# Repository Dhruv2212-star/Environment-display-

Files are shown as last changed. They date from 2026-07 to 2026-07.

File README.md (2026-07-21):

**The project is divided into 8 major parts**  
lets understand each component's function one by one in a block to see what function they have in the circuit.   
1. Block 1 – USB Input & Protection  

| Ref | Component | Role in the Circuit |
| --- | --- | --- |
| J1  | USB-C Receptacle | Receives 5 V power and USB data from the host PC. |
| D1  | TVS Diode | Protects the board from ESD and voltage spikes coming through the USB connector. |
| F1  | Polyfuse | Limits current during short circuits and protects the USB port from overcurrent damage. |
| R1  | 5.1 kΩ | USB-C CC1 pull-down resistor to advertise the board as a power sink. |
| R2  | 5.1 kΩ | USB-C CC2 pull-down resistor to advertise the board as a power sink. |

2. Block 2 – 3.3 V Power Supply

| Ref | Component | Role in the Circuit |
| --- | --- | --- |
| U1  | TPS62162 | Converts the USB 5 V input into a stable 3.3 V supply with high efficiency. |
| L1  | 2.2 µH Inductor | Stores energy during switching and smooths the regulator output current. |
| C1  | 10 µF | Input bulk capacitor that stabilizes the 5 V input to the regulator. |
| C2  | 100 nF | High-frequency input bypass capacitor that filters switching noise. |
| C4  | 4.7 µF | Main output capacitor that stabilizes the 3.3 V output voltage. |
| C9  | 100 µF | Bulk output capacitor that supplies transient current to the ESP32 and peripherals. |
| R3  | 100 kΩ | Feedback resistor used by the regulator to maintain the correct output voltage. |

3. Block 3 – USB to UART Interface  

| Ref | Component | Role in the Circuit |
| --- | --- | --- |
| U2  | CP2102N | Converts USB communication into UART for programming and serial communication with the ESP32. |
| C3  | 100 nF | Decouples the CP2102N supply to reduce high-frequency noise. |
| C5  | 1 µF | Stabilizes the USB VBUS supply for the CP2102N. |
| C6  | 1 µF | Stabilizes the internal regulator output of the CP2102N. |

4. Block 4 – ESP32 Auto-Programming Circuit  

| Ref | Component | Role in the Circuit |
| --- | --- | --- |
| Q1  | MMBT3904 | Uses the RTS signal to automatically reset the ESP32. |
| Q2  | MMBT3904 | Uses the DTR signal to place the ESP32 into bootloader mode automatically. |
| R11 | 10 kΩ | Pull-up resistor for the ESP32 EN pin. |
| R12 | 10 kΩ | Pull-up resistor for the ESP32 GPIO0 (BOOT) pin. |
| SW1 | Push Button | Manual reset button for the ESP32. |
| SW2 | Push Button | Manual bootloader button for programming mode. |

5. Block 5 – ESP32 Module  

| Ref | Component | Role in the Circuit |
| --- | --- | --- |
| U3  | ESP32-WROOM-32E | Main microcontroller that reads sensors, stores data, communicates over USB, and controls the entire system. |
| C10 | 100 nF | Local decoupling capacitor placed close to the ESP32 power pin. |
| C11 | 100 nF | Additional high-frequency decoupling capacitor for stable ESP32 operation. |
| C16 | 10 µF | Bulk capacitor that supports sudden current demands from the ESP32's Wi-Fi and Bluetooth radio. |

6.  Block 6 – Environmental Sensors

(a) BME280  

| Ref | Component | Role in the Circuit |
| --- | --- | --- |
| U4  | BME280 | Measures temperature, humidity, and atmospheric pressure. |
| C12 | 100 nF | Filters supply noise to improve sensor accuracy. |

(b)  BH1750  

| Ref | Component | Role in the Circuit |
| --- | --- | --- |
| U4  | BME280 | Measures temperature, humidity, and atmospheric pressure. |
| C12 | 100 nF | Filters supply noise to improve sensor accuracy. |

(c) RTC  

| Ref | Component | Role in the Circuit |
| --- | --- | --- |
| U6  | DS3231M | Maintains accurate date and time, even when USB power is removed. |
| BT1 | CR2032 Battery | Keeps the RTC running during power loss. |
| C15 | 100 nF | Decouples the RTC power supply. |

7. Block 7 – microSD Storage  

| Ref | Component | Role in the Circuit |
| --- | --- | --- |
| J3  | MicroSD Socket | Stores logged environmental data on a removable SD card. |
| R9  | Pull-up resistor | Pulls the Card Detect line to a defined logic level when no card is inserted. |

8. Block 8 – User Interface

| Ref | Component | Role in the Circuit |
| --- | --- | --- |
| J2  | OLED Header | Connects the external OLED display over the I²C bus. |
| D2  | Status LED  | Indicates board status such as power or firmware activity. |
| R10 | 1 kΩ | Limits current through the status LED to protect it from excessive current. |

# Schematic 
schematic

# Final traced PCB 

PCB traced

# 3D view of the assumed PCB look 

3D png

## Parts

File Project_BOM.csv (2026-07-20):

Reference | Value | Quantity
R4 | 1 kΩ | 1
R5, R6, R11, R12 | 10 kΩ | 4
C1, C3, C4, C10 | 10 µF | 4
R3 | 100 kΩ | 1
C2, C6, C8, C9, C11, C12 | 100 nF | 6
L1 | 2.2 µH | 1
R10 | 330 Ω | 1
R7, R8 | 4.7 kΩ | 2
C5, C7 | 4.7 µF | 2
R1, R2 | 5.1 kΩ, 1% | 2
U4 | BME280 | 1
BT1 | Battery_Cell | 1
C13, C14, C15, C16 | C | 4
U2 | CP2102N-Axx-xQFN20 | 1
J2 | Conn_01x04 | 1
J4 | Conn_01x04_Pin | 1
J5 | Conn_01x06_Pin | 1
U6 | DS3231M | 1
D1 | D_TVS | 1
U3 | ESP32-WROOM-32 | 1
D2 | LED | 1
Q1, Q2 | MMBT3904 | 2
J3 | Micro_SD_Card_Det1 | 1
F1 | Polyfuse | 1
R9 | R | 1
SW1, SW2 | SW_Push | 2
J1 | USB_C_Receptacle | 1
U1, U5 | ~ | 2

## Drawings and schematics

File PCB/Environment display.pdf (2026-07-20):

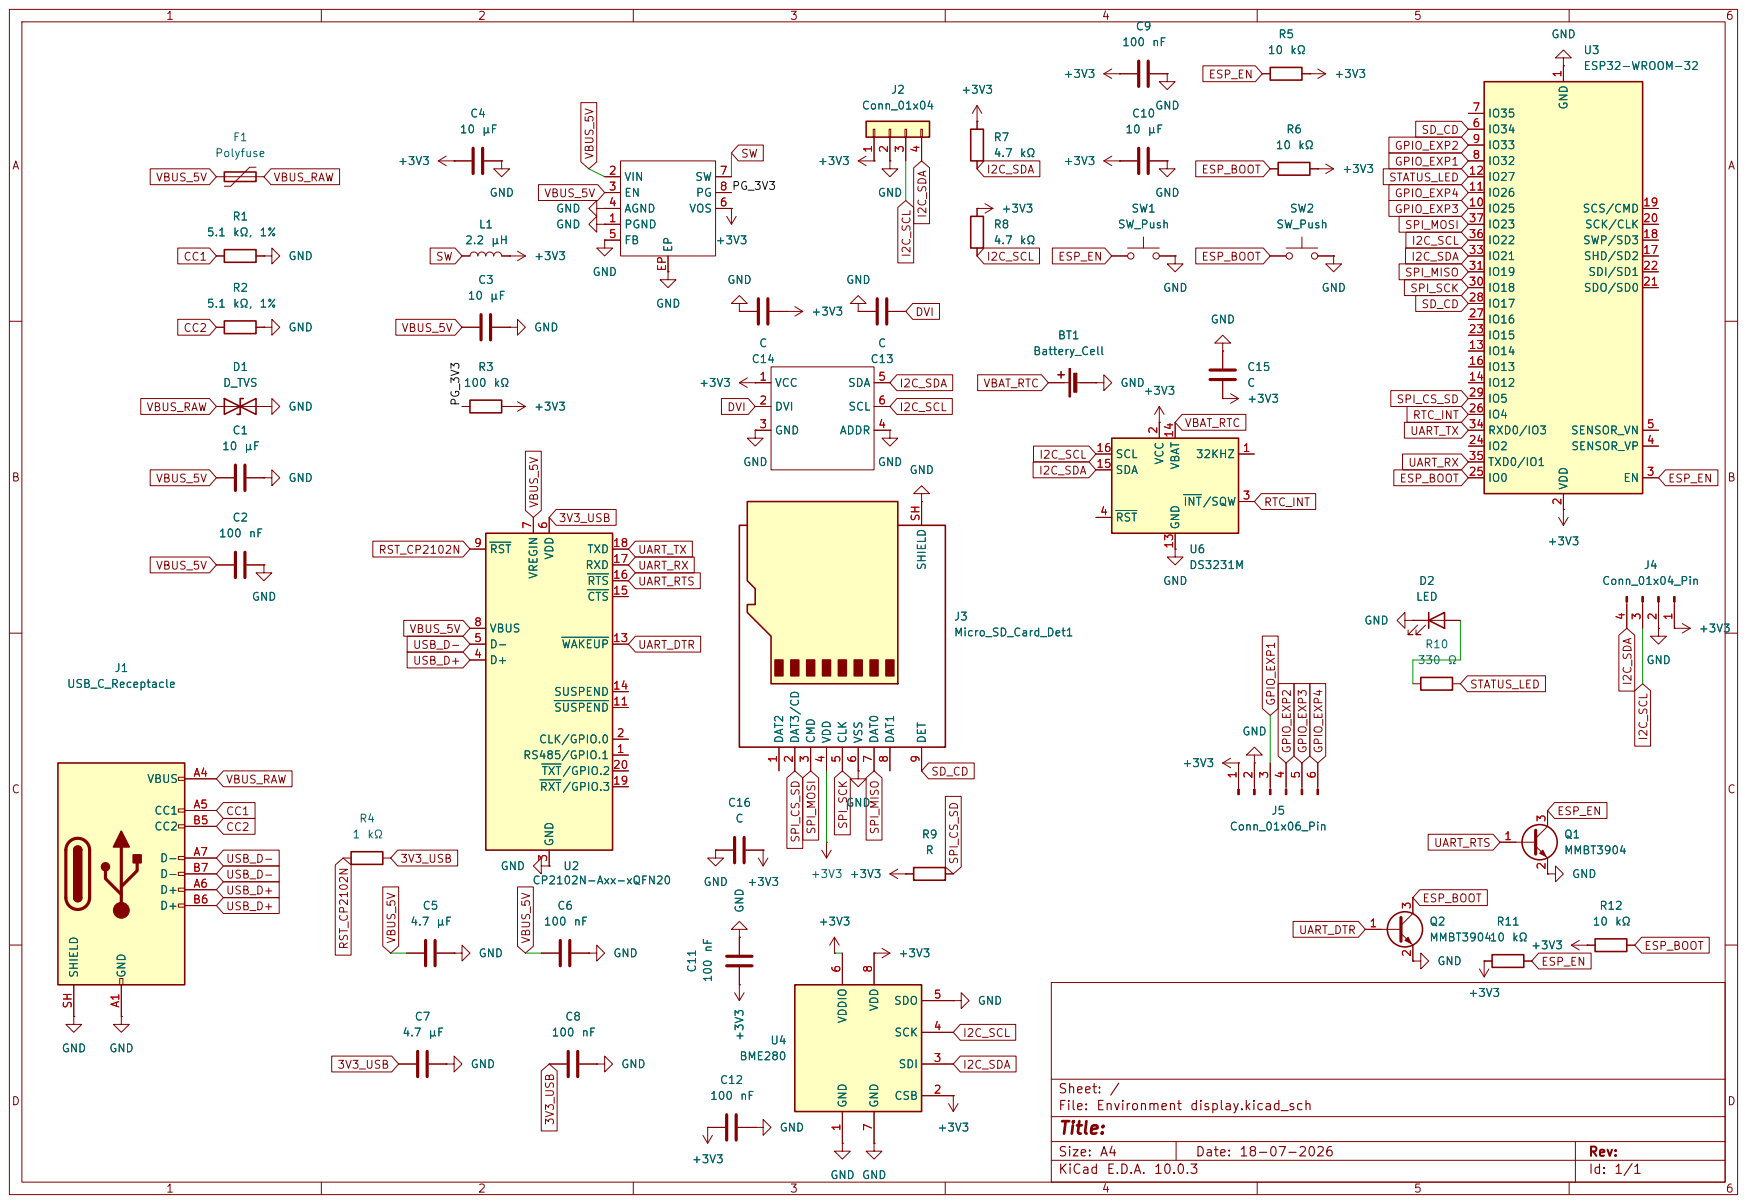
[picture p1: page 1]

Size: A4 | Rev:
KiCad E.D.A. 10.0.3 | Id: 1/1

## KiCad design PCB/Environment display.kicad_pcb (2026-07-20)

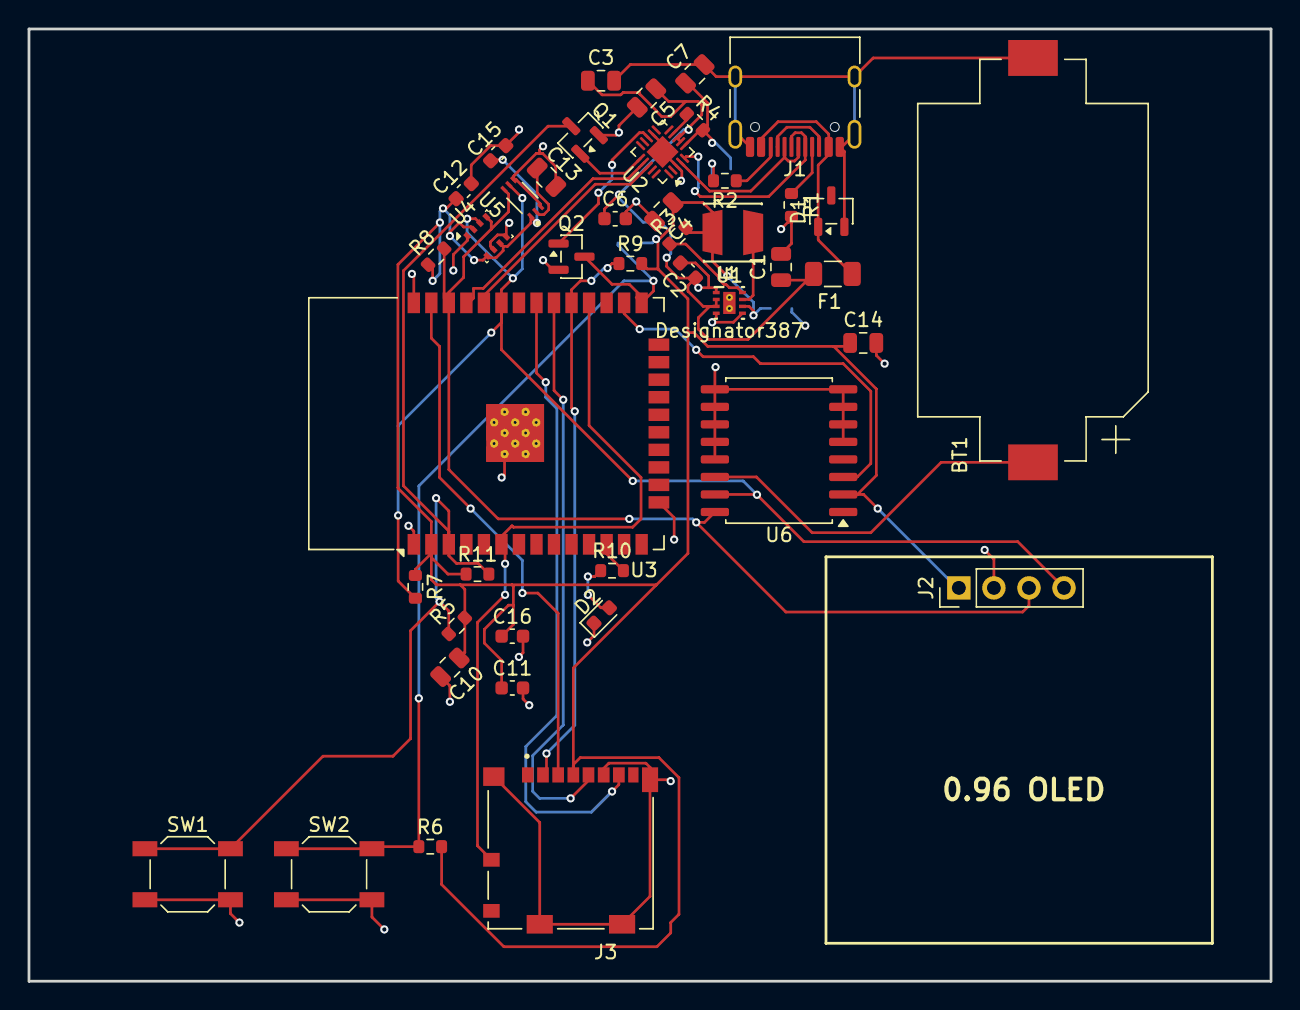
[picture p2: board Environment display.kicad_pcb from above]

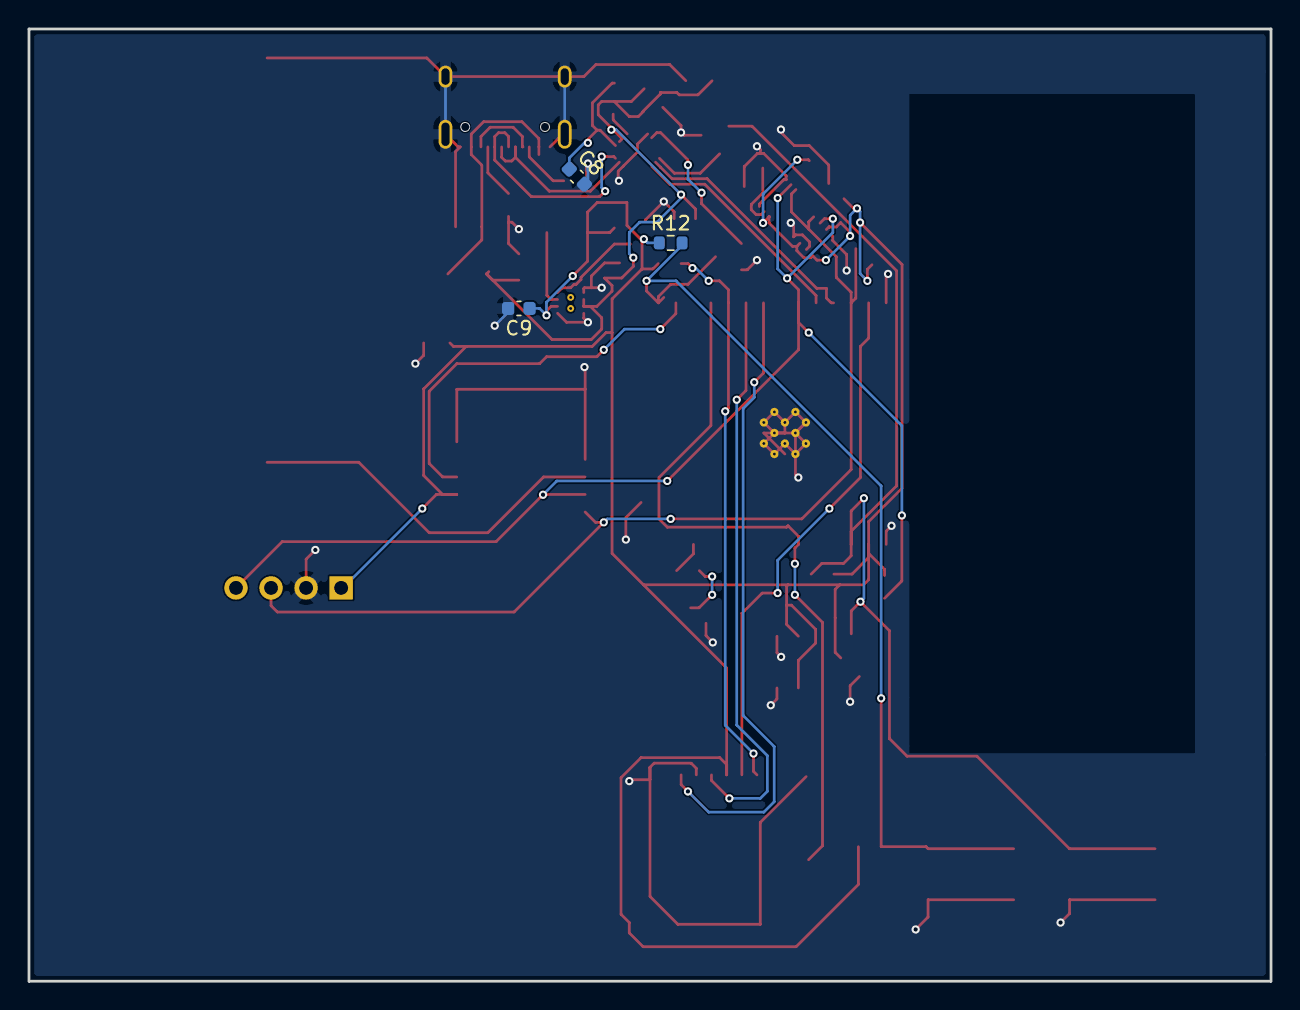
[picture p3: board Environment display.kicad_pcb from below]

Board: 2 copper layers, 90.0 x 69.0 mm, 46 parts (3 on the bottom side), 30 nets.

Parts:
BT1: Battery_Cell; BatteryHolder_Keystone_1060_1x2032
C1, C3, C4, C10: 10 µF; C_0805_2012Metric
C2, C6, C8, C9, C11, C12: 100 nF; C_0603_1608Metric
C5, C7: 4.7 µF; C_0805_2012Metric
C13, C14: C; C_0805_2012Metric
C15, C16: C; C_0603_1608Metric
D1: D_TVS; SOT-23-3
D2: LED; LED_0603_1608Metric
F1: Polyfuse; Fuse_1206_3216Metric
J1: USB_C_Receptacle; USB_C_Receptacle_HRO_TYPE-C-31-M-12
J2: Conn_01x04; PinHeader_1x04_P2.54mm_Vertical
J3: Micro_SD_Card_Det1; MOLEX_104031-0811
L1: 2.2 µH; MURATA_LQH44PN2R2MPRL
Q1, Q2: MMBT3904; SOT-23
R1, R2: 5.1 kΩ, 1%; R_0603_1608Metric
R3: 100 kΩ; R_0603_1608Metric
R4: 1 kΩ; R_0603_1608Metric
R5, R6, R11, R12: 10 kΩ; R_0603_1608Metric
R7, R8: 4.7 kΩ; R_0603_1608Metric
R9: R; R_0603_1608Metric
R10: 330 Ω; R_0603_1608Metric
SW1, SW2: SW_Push; SW_SPST_SKQG_WithoutStem
U1: DSG0008A
U2: CP2102N-Axx-xQFN20; QFN-20-1EP_3x3mm_P0.4mm_EP1.65x1.65mm
U3: ESP32-WROOM-32
U4: BME280; Bosch_LGA-8_2.5x2.5mm_P0.65mm_ClockwisePinNumbering
U5: XDCR_BH1750FVI-TR
U6: DS3231M; SOIC-16W_7.5x10.3mm_P1.27mm

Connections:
3V3_USB: C7.1, C8.1, R4.2, U2.6 (VDD)
+3V3: C4.1, C9.1, C10.1, C11.1, C12.1, C14.1, C15.1, C16.1, J2.1, J3.4 (VDD), L1.2, R3.2, R5.2, R6.2, R7.1, R8.1, R9.2, R11.1, R12.1, U1.6 (VOS), U3.2 (VDD), U4.2 (CSB), U4.6 (VDDIO), U4.8 (VDD), U5.1 (VCC), U6.2 (VCC)
/PG_3V3: R3.1, U1.8 (PG)
CC1: J1.A5 (CC1), R1.1
CC2: J1.B5 (CC2), R2.1
DVI: C13.1, U5.2 (DVI)
ESP_BOOT: Q2.3 (C), R6.1, R12.2, SW2.1, U3.25 (IO0)
ESP_EN: Q1.3 (C), R5.1, R11.2, SW1.1, U3.3 (EN)
GND: BT1.2 (-), C1.2, C2.2, C3.2, C4.2, C5.2, C6.2, C7.2, C8.2, C9.2, C10.2, C11.2, C12.2, C13.2, C14.2, C15.2, C16.2, D1.2 (A2), D2.1 (K), J1.A1 (GND), J1.A12 (GND), J1.B1 (GND), J1.B12 (GND), J1.SH (SHIELD), J2.2, J3.6 (VSS), J3.SH (SHIELD), Q1.2 (E), Q2.2 (E), R1.2, R2.2, SW1.2, SW2.2, U1.1 (PGND), U1.4 (AGND), U1.5 (FB), U1.EP, U2.3 (GND), U2.12 (GND), U2.21 (GND), U3.1 (GND), U3.15 (GND), U3.38 (GND), U3.39 (GND), U4.1 (GND), U4.5 (SDO), U4.7 (GND), U5.3 (GND), U5.4 (ADDR), U6.5 (GND), U6.6 (GND), U6.7 (GND), U6.8 (GND), U6.9 (GND), U6.10 (GND), U6.11 (GND), U6.12 (GND), U6.13 (GND)
I2C_SCL: J2.3, R8.2, U3.36 (IO22), U4.4 (SCK), U5.6 (SCL), U6.16 (SCL)
I2C_SDA: J2.4, R7.2, U3.33 (IO21), U4.3 (SDI), U5.5 (SDA), U6.15 (SDA)
unnamed: D2.2 (A), R10.1
RST_CP2102N: R4.1, U2.9 (~RST)
RTC_INT: U3.26 (IO4), U6.3 (~INT/SQW)
SD_CD: J3.9 (DET), U3.6 (IO34), U3.28 (IO17)
SPI_CS_SD: J3.2 (DAT3/CD), R9.1, U3.29 (IO5)
SPI_MISO: J3.7 (DAT0), U3.31 (IO19)
SPI_MOSI: J3.3 (CMD), U3.37 (IO23)
SPI_SCK: J3.5 (CLK), U3.30 (IO18)
STATUS_LED: R10.2, U3.12 (IO27)
SW: L1.1, U1.7 (SW)
UART_DTR: Q2.1 (B), U2.13 (~WAKEUP)
UART_RTS: Q1.1 (B), U2.16 (~RTS)
UART_RX: U2.17 (RXD), U3.35 (TXD0/IO1)
UART_TX: U2.18 (TXD), U3.34 (RXD0/IO3)
USB_D+: J1.A6 (D+), J1.B6 (D+), U2.4 (D+)
USB_D−: J1.A7 (D-), J1.B7 (D-), U2.5 (D-)
VBAT_RTC: BT1.1 (+), U6.14 (VBAT)
VBUS_5V: C1.1, C2.1, C3.1, C5.1, C6.1, F1.1, U1.2 (VIN), U1.3 (EN), U2.7 (VREGIN), U2.8 (VBUS)
VBUS_RAW: D1.1 (A1), F1.2, J1.A4 (VBUS), J1.A9 (VBUS), J1.B4 (VBUS), J1.B9 (VBUS)

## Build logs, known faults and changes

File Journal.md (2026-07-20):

# Schematic  | 3 hours 
Lapse- https://lapse.hackclub.com/timelapse/Z0Db5BN6gkWm  
Lapse- https://lapse.hackclub.com/timelapse/cz-Wl3GnSz1p  
1. Power  | 15 mins  



2. Making custom symbol as i could not find a correct symbol for the footprint i selected | 20 mins  



3. Block 2: buck converter module for power | 15 mins



4. Block 3: | 10 mins  

 18 07 2026_12 35 26_REC

5. Block 4 – ESP32 Core | 30 mins  

block 4

6. block 5- | 15 mins   

block 5

7. block 6 | 15 mins  

block6

8. **went into an unexpected error with the schematic with all the connections so i had to go through all the connections and re verify all the data sheets to prevent wrong connection and i had to also make sure the chip i used was compatible for my project. | 45 mins (i forgot to switch the window so all you can see in the last 45 mins of lapse is the schematic)**  

9. block 7 BH1750 Ambient Light Sensor | 10 mins
    
block 7

10. block 8: DS3231 RTC | 30 mins  

block 8

11. block 9: OLED Connector | 5 mins  

block 9

12. block 10 microSD Interface | 10 mins  

block 10

13. block 11 Status LED | 5 mins  

block 11

14. block 12 gpio expansion headers | 10 mins  

block 12

------------------------------------------------------------------------------------------------------------------------------------------

# Footprint assignment | 30 mins  

searched for the correct parts online and had to download their footprints  
Lapse- https://lapse.hackclub.com/timelapse/WOPtqokwvo3c  

# PCB tracing  | 2 hours 30 mins 

took me a lot of time because i had to recheck every connection because of the number of connections needed to be made, they crosed 150 connections and there were 2-3 possible connections so i had to revise the schematic one or twice and change the footprints and symbols too  
Lapse 1- https://lapse.hackclub.com/timelapse/publish/9UZKi9gmFOcU  
Lapse 2- https://lapse.hackclub.com/timelapse/publish/AlIP1qHjNjiN  
PCB traced

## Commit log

2026-07-18 schematic till block 6
2026-07-20 PCB tracing and Footprints assignment
2026-07-20 schematic, PCB,Production files added
    [BOM.csv, Environment display.kicad_pcb, Environment display.kicad_sch]
2026-07-20 updated the BOM
    [BOM.csv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]
